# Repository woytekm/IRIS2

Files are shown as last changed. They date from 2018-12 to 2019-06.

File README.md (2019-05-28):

IRIS2 network radio project. This repository will contain all the necessary information required to build the unit.

Project images and video clips: https://drive.google.com/open?id=105BILNTAdYNRVomJvfbO0CPW3QA1uIXu

Currently we have here:
 - Code for core Iris application along with all necessary system scripts 
 - KiCad projects/schematics for all PCB's
 - STL's of all parts of the IRIS2 case
 - Some initial documentation
 
What we need to add:
 - More documentation
 - Detailed assembly instructions for all the PCB's and the unit itself
 - Detailed BOM for all of the PCB's, and additional stuff required to assemble the unit itself
 - Detailed instructions on how to make your own copy of IRIS2 firmware based on Raspbian (and/or firmware images)

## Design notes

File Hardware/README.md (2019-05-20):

This directory contains KiCad Projects of IRIS2 boards. Projects also contain Gerber files and schematics in PDF format.

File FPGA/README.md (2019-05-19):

This is JTAG indirect configuration file for Altera Cyclone IV EP4CE10 with EPCS16 flash memory.
Board used in project is from aliexpress.com "FPGA Board Store" seller.

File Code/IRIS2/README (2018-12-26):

packages needed on raspbian:

sudo apt-get install libxml2
sudo apt-get install libxml2-dev
sudo apt-get install libcurl3
sudo apt-get install libcurl4-openssl-dev

libbass-hardfp ARM

picotts:

sudo apt-get install libpopt-dev
sudo apt-get install libexpat1-dev

Hardware:

Raspberry Pi A+

speaker - Visaton FRWS 5 R

opamp 
 - NE5532

PSU board for opamp: 
 - LM2577 S ADJ
 - ICL7660
 - solid state relay (P/N?) 

RTC + NVRAM board
 - DS1397
 - Atmel 24C512 DIP8 (64KB)

display:
 - Winstar WEH001602

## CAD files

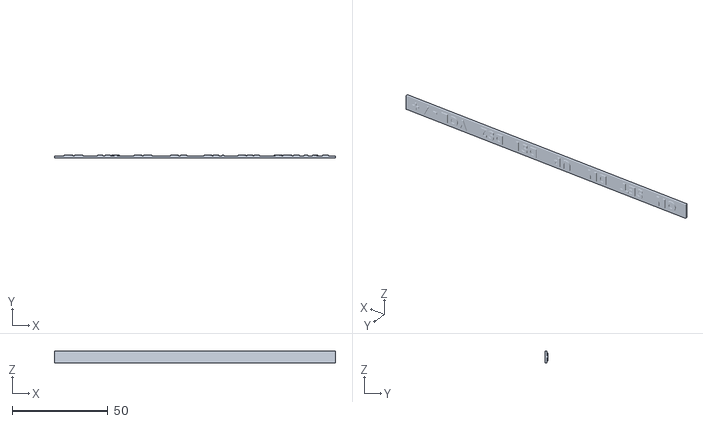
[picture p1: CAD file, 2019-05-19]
STL/2019-05-19/Main Unit - key descriptions v3.stl
147.0 x 1.60 x 6.50

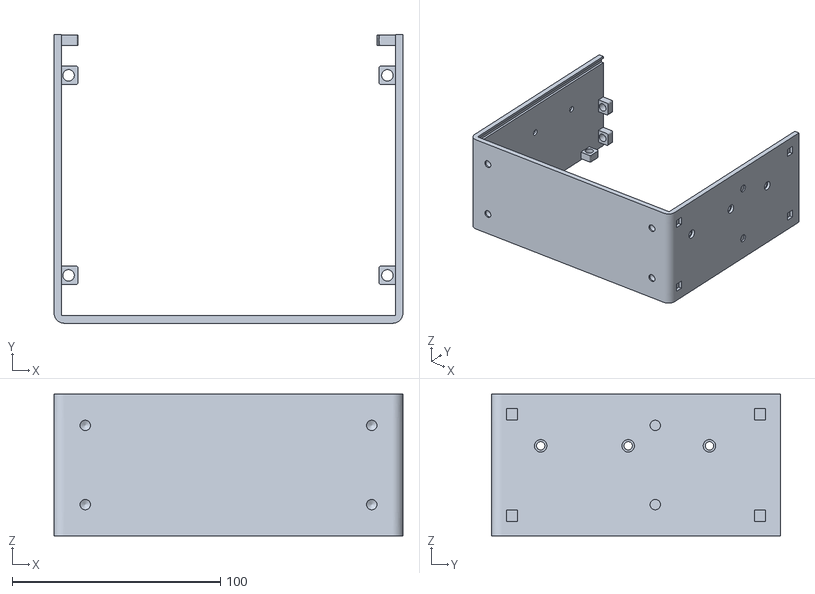
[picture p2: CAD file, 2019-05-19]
STL/2019-05-19/Main unit external shell v15.stl
167.5 x 138.5 x 68.0

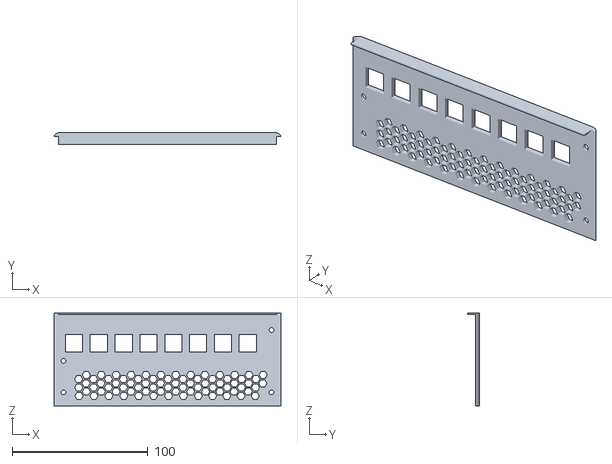
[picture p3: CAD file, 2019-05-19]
STL/2019-05-19/Main unit - top cover v24.stl
167.5 x 9.00 x 68.5

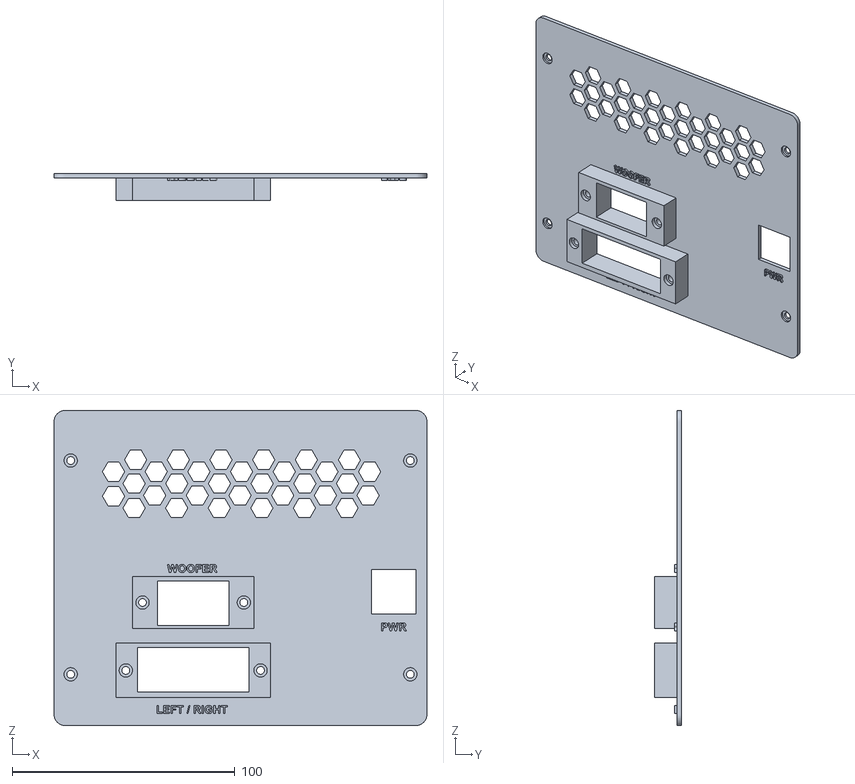
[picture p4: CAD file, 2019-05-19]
STL/2019-05-19/Main Unit - back cover.stl
167.5 x 12.1 x 141.5

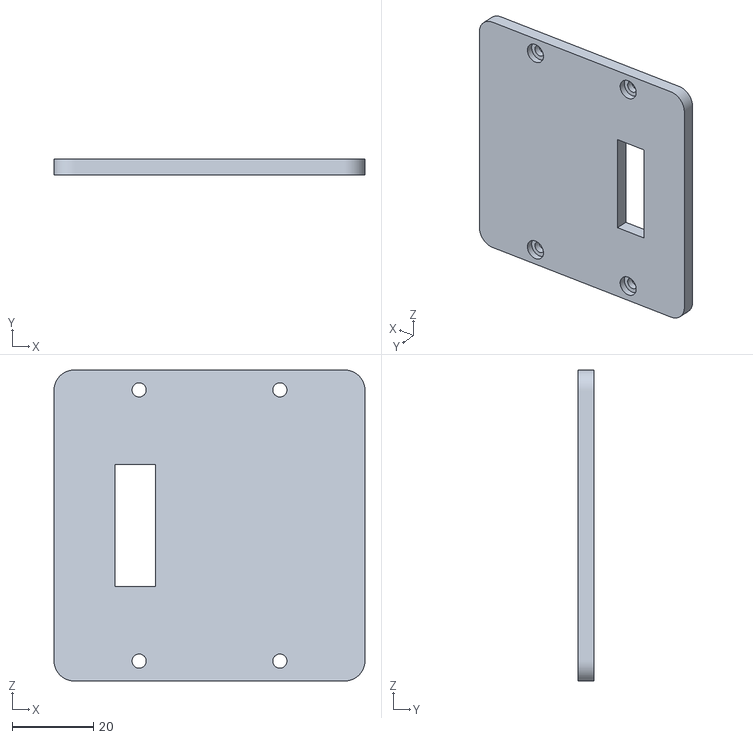
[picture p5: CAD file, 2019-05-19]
STL/2019-05-19/Satellite speaker back cover small v4.stl
76.7 x 4.00 x 76.7

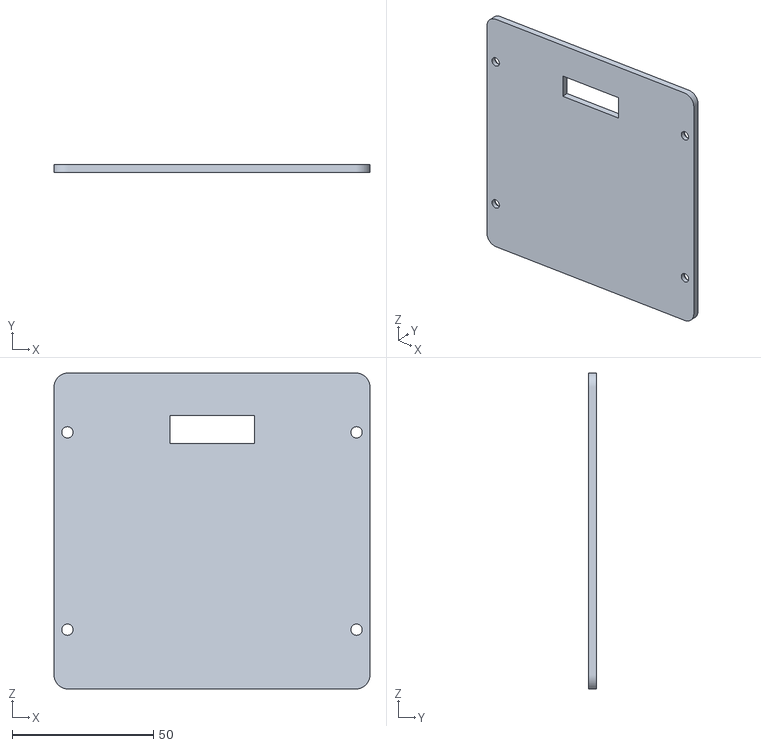
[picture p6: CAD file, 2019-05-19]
STL/2019-05-19/Subwoofer back cover v4.stl
111.8 x 3.00 x 111.8

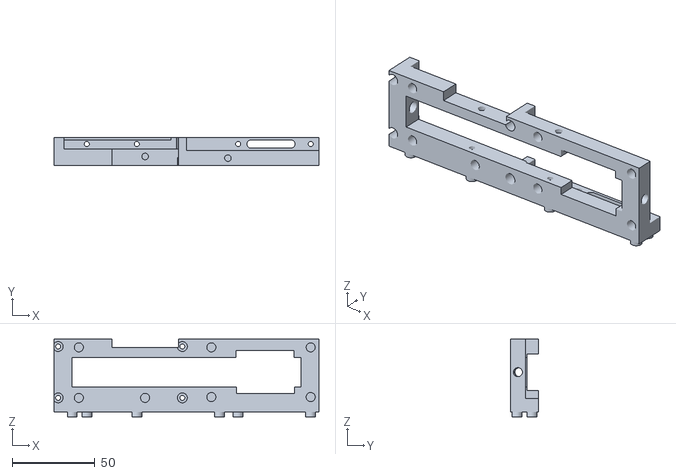
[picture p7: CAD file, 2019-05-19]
STL/2019-05-19/Upper LCD frame 160x40.stl
160.0 x 17.0 x 47.0

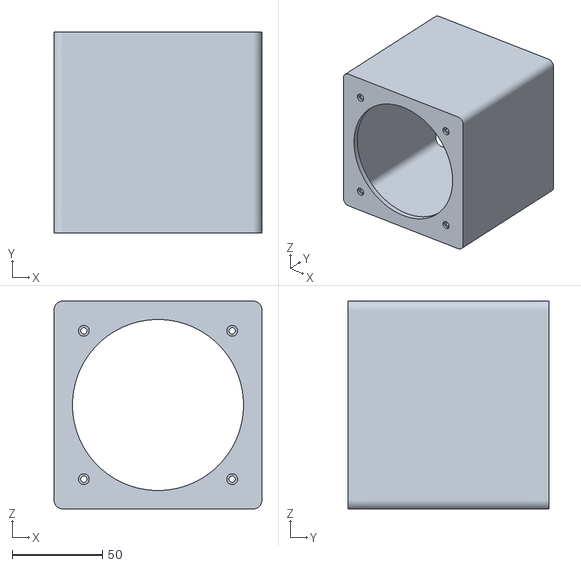
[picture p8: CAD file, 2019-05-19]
STL/2019-05-19/Subwoofer v9.stl
115.0 x 111.0 x 115.0

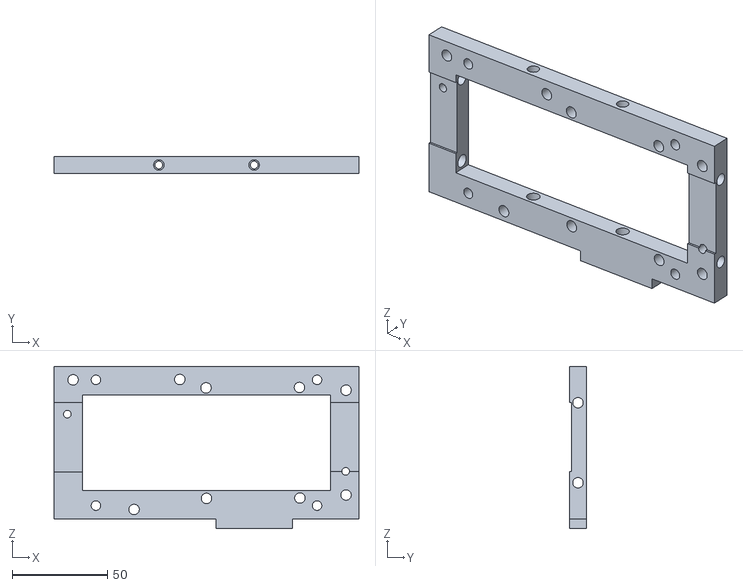
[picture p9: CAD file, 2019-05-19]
STL/2019-05-19/32x64 P2.5 mount frame single.stl
160.0 x 9.00 x 85.0

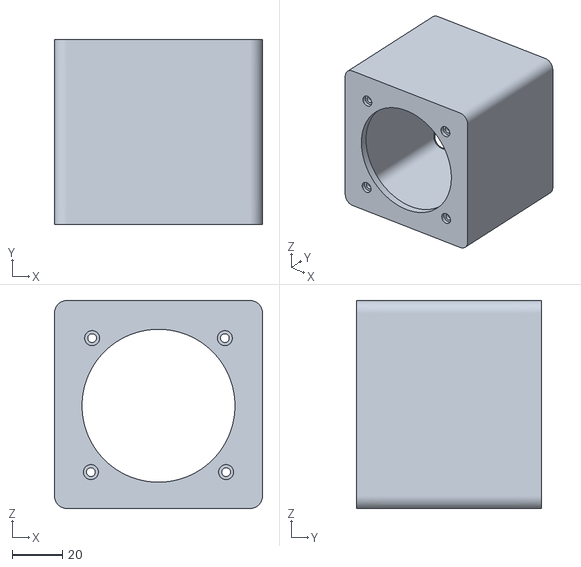
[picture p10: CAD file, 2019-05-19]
STL/2019-05-19/Satellite speaker small v7.stl
83.0 x 74.0 x 83.0

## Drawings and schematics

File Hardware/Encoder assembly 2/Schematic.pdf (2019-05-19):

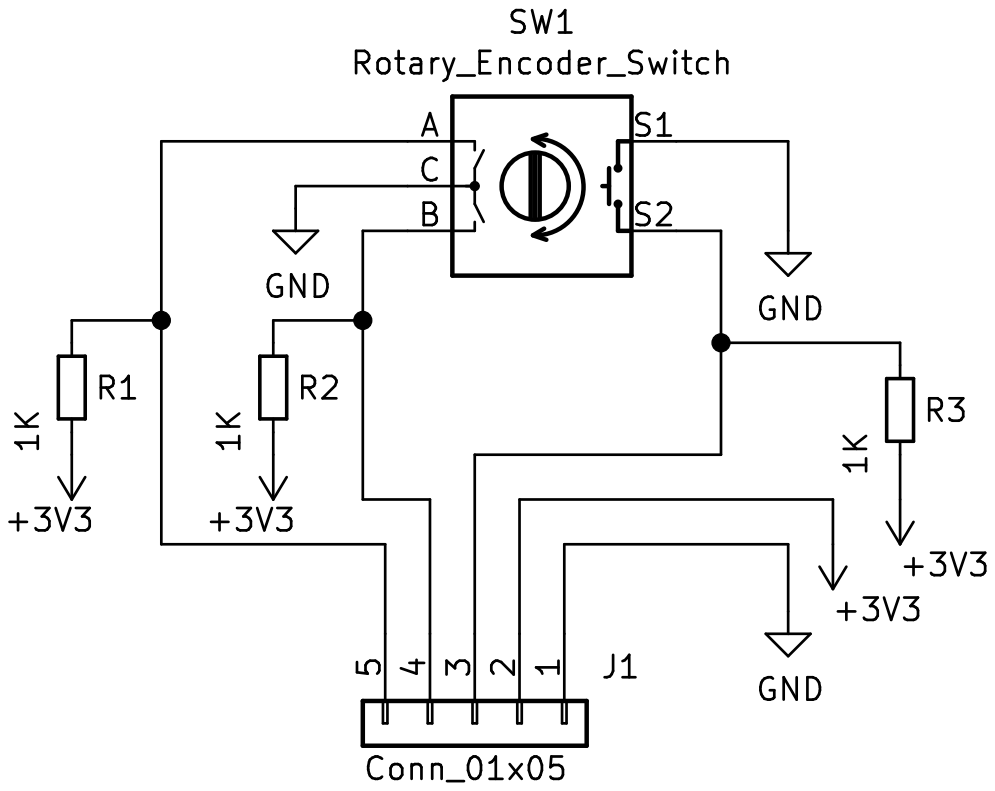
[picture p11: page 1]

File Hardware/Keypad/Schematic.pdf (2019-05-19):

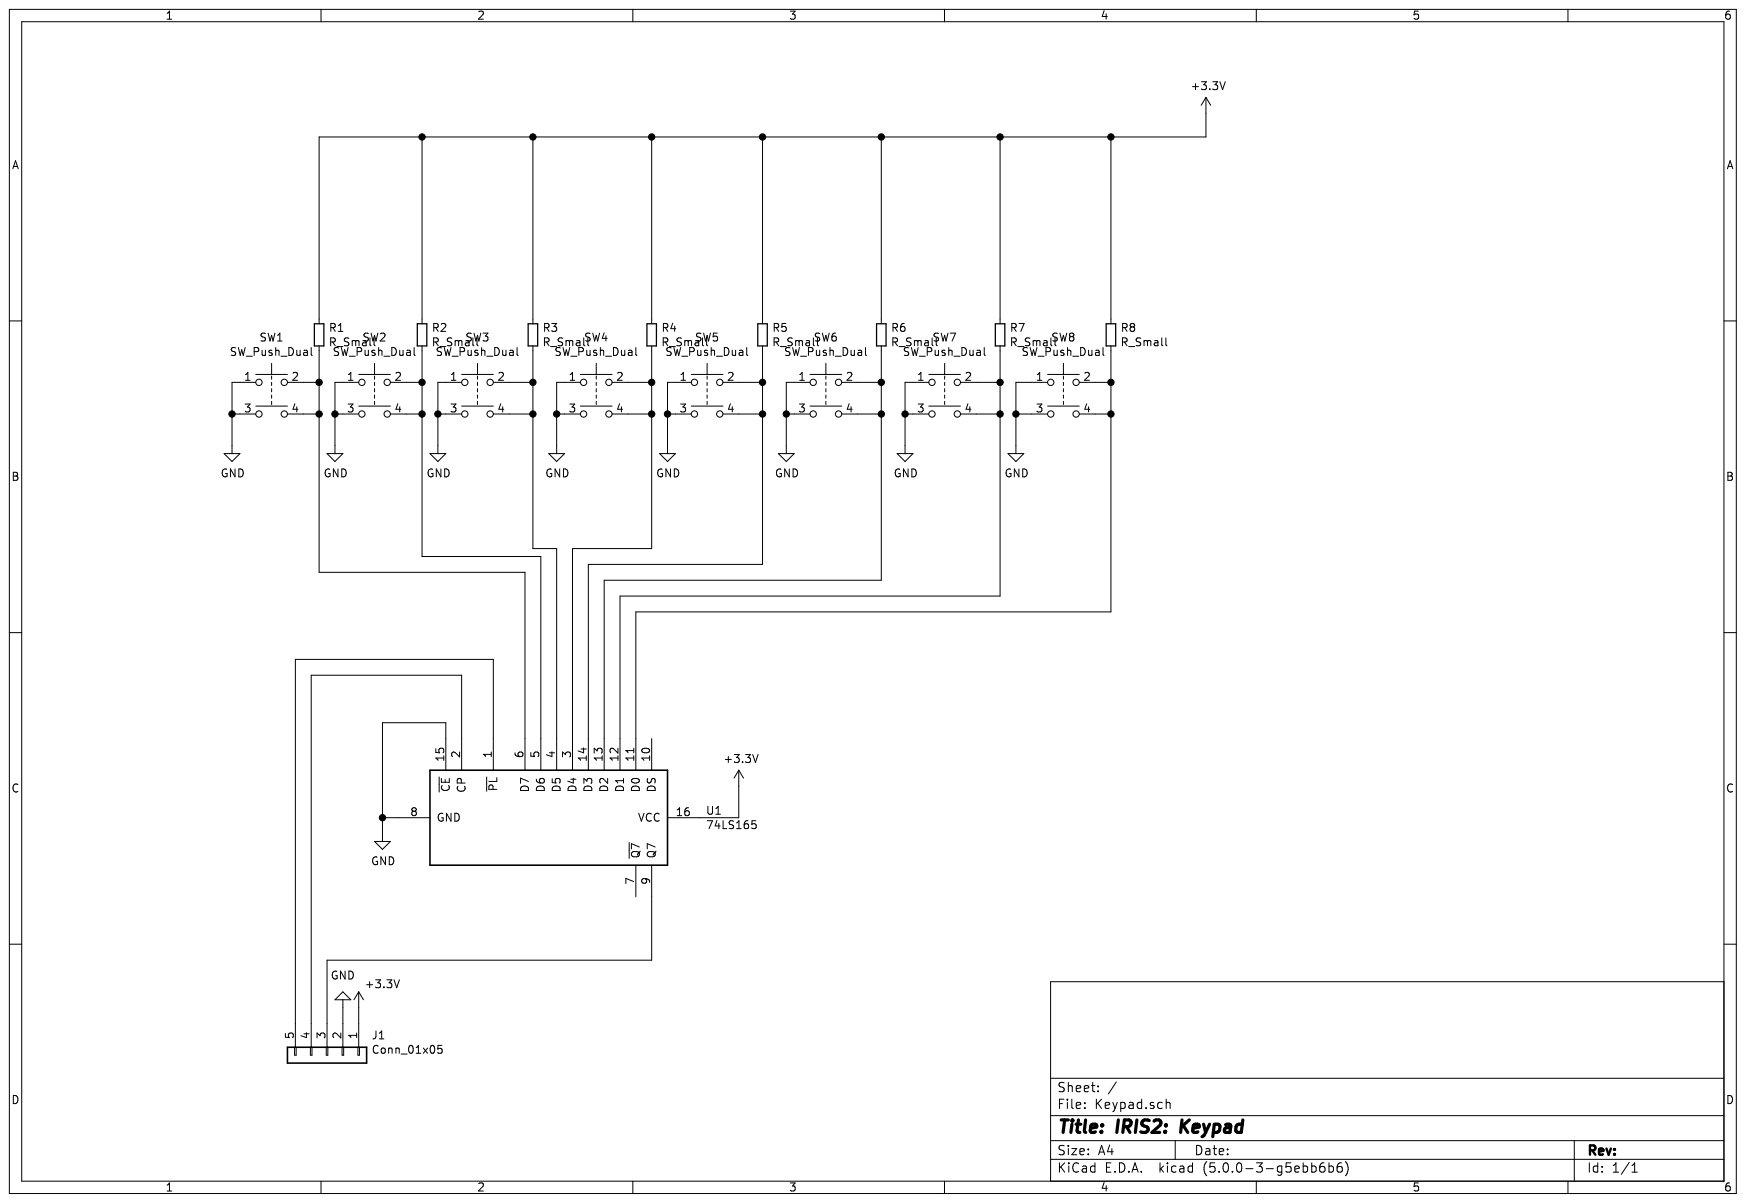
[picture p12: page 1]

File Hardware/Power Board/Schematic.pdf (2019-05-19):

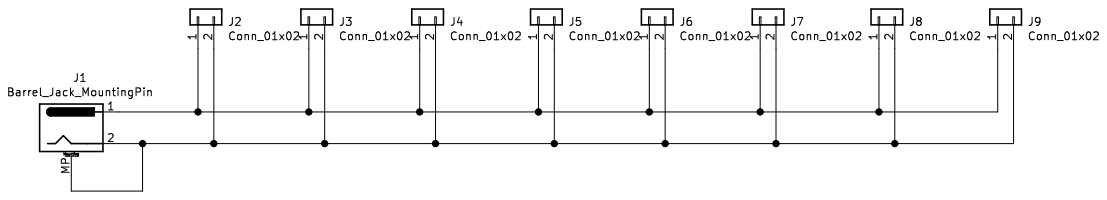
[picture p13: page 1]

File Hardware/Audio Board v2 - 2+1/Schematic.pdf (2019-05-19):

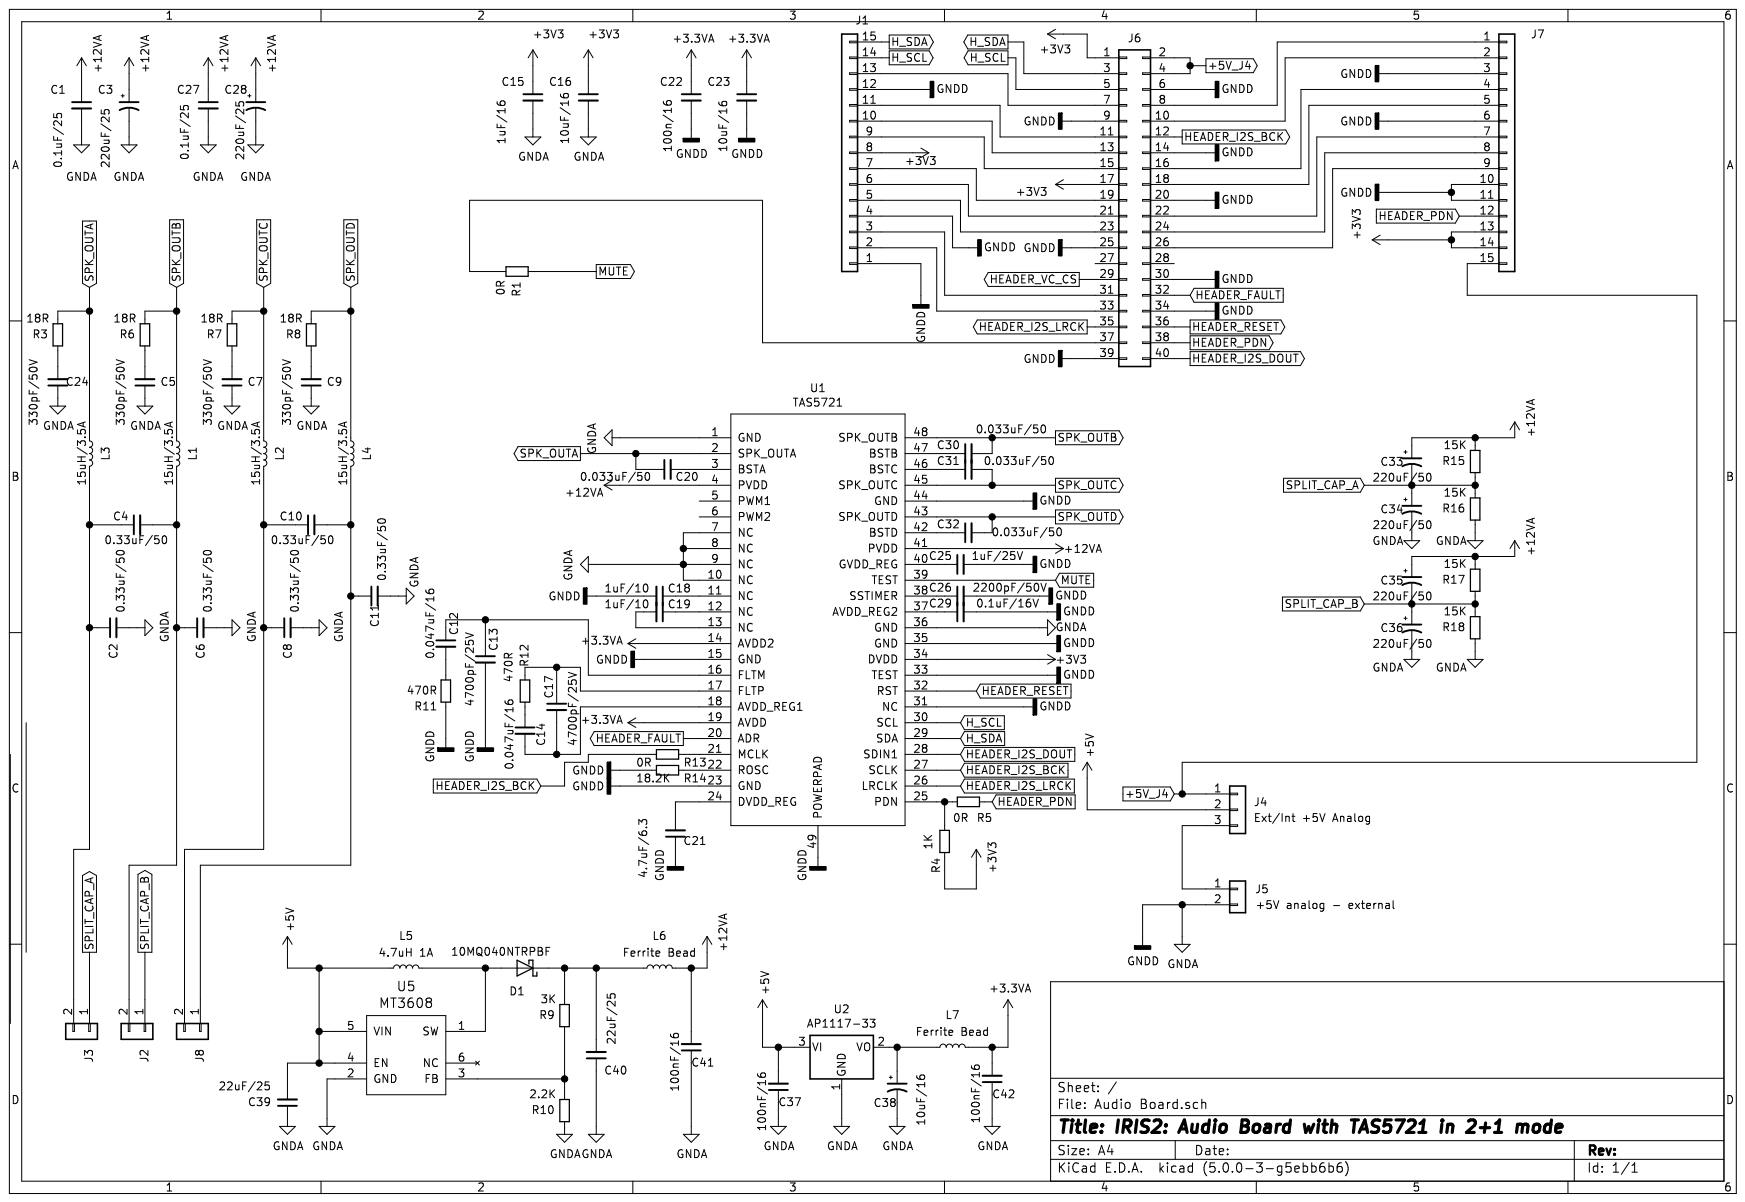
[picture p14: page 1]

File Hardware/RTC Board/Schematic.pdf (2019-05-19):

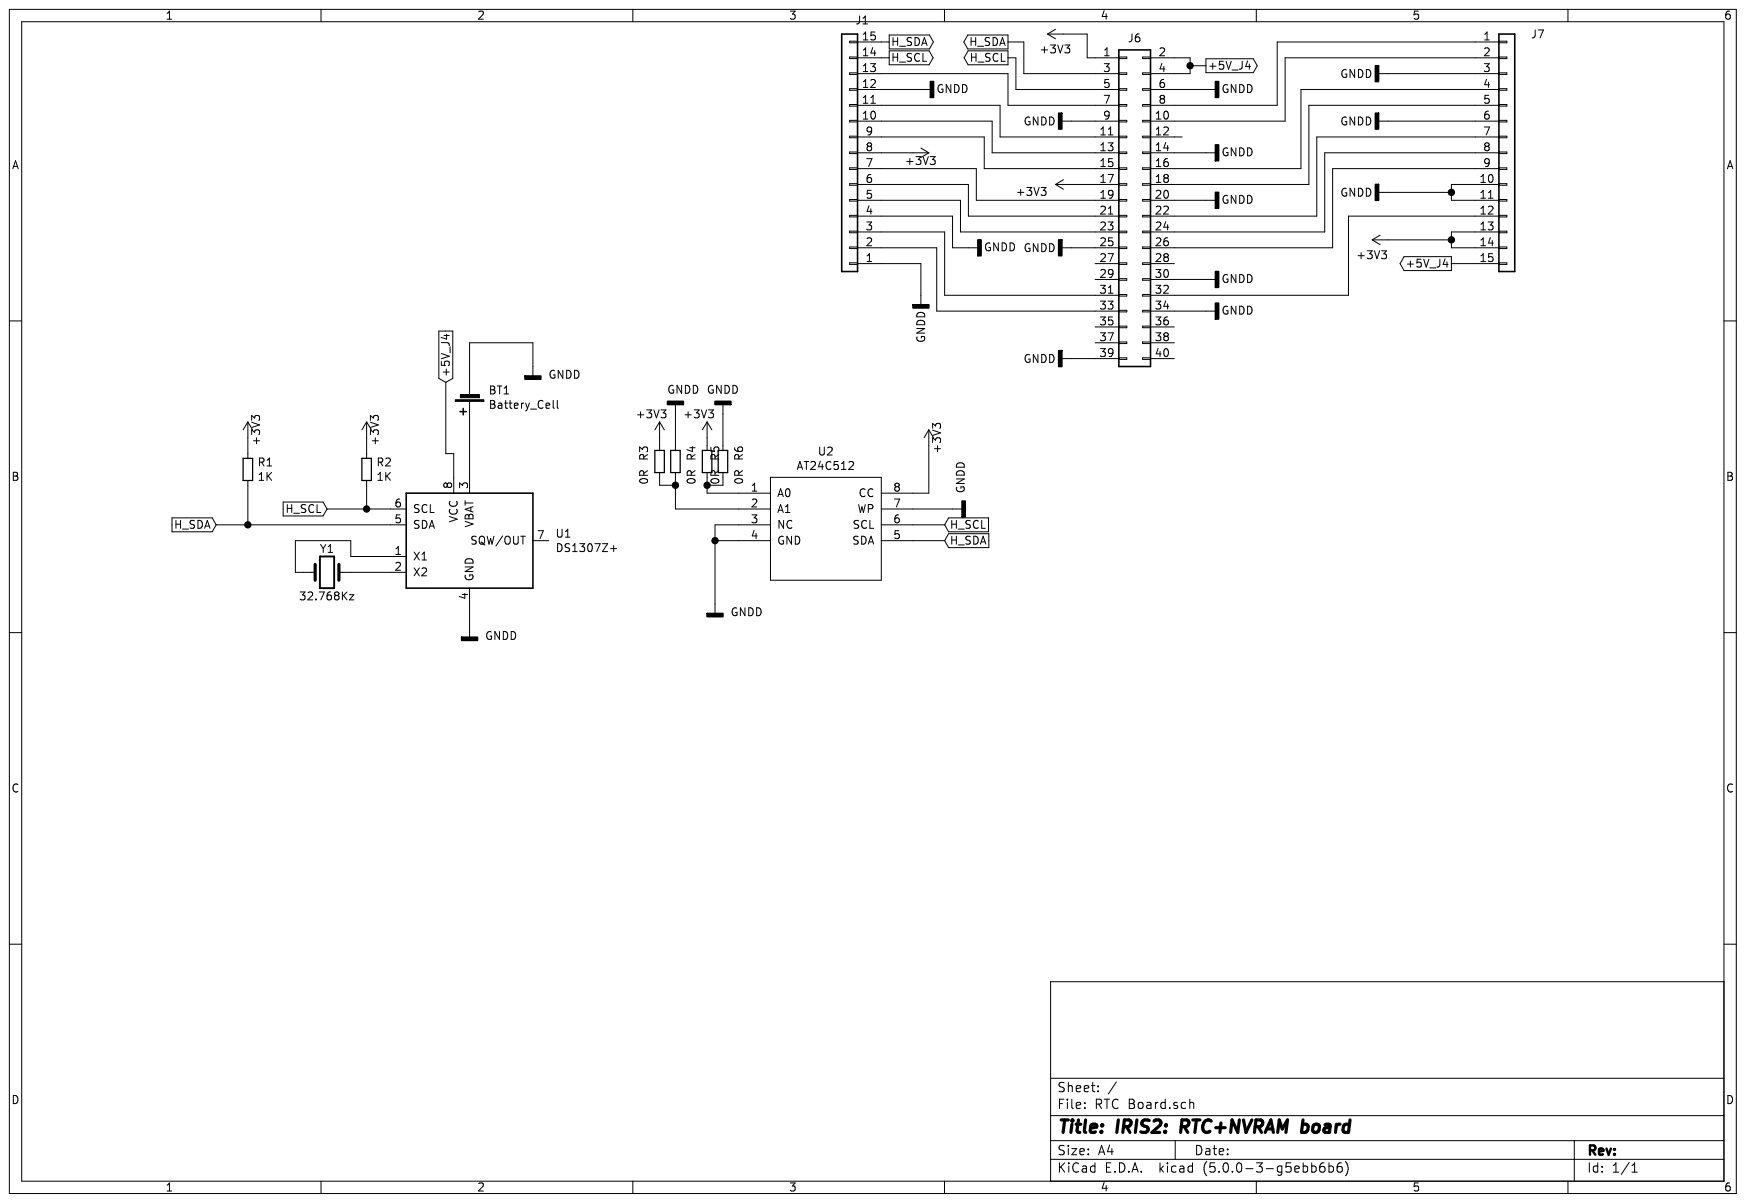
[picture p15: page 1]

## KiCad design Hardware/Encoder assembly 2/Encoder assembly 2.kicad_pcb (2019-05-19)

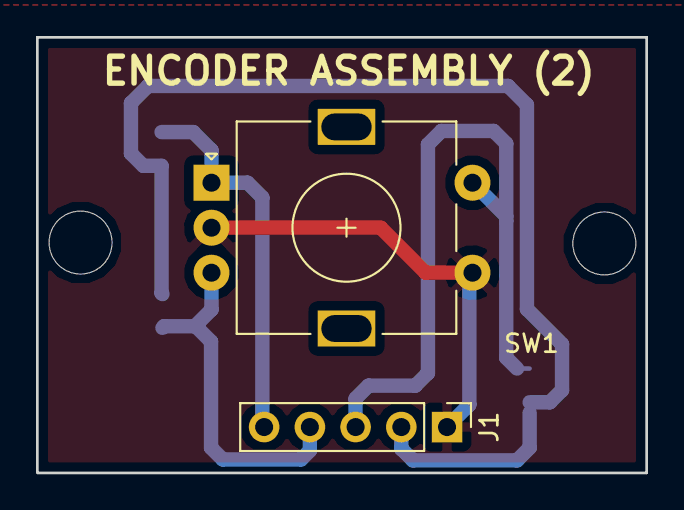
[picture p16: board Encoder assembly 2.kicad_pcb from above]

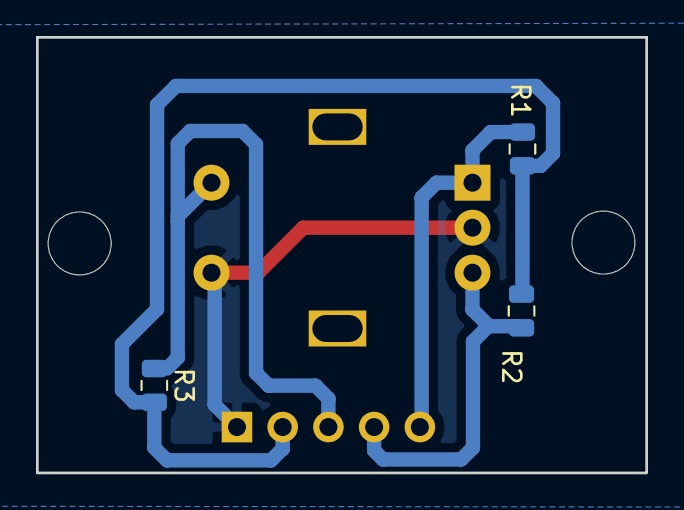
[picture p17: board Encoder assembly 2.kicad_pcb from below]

Board: 2 copper layers, 33.8 x 24.2 mm, 5 parts (3 on the bottom side), 5 nets.

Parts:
J1: Conn_01x05; PinHeader_1x05_P2.54mm_Vertical
R1, R2, R3: R_Small; R_0805_2012Metric
SW1: Rotary_Encoder_Switch; RotaryEncoder_Alps_EC11E-Switch_Vertical_H20mm

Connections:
+3V3: J1.2, R1.2, R2.2, R3.2
GND: J1.1, SW1.C, SW1.S1
unnamed: J1.3, R3.1, SW1.S2
unnamed: J1.4, R2.1, SW1.B
unnamed: J1.5, R1.1, SW1.A

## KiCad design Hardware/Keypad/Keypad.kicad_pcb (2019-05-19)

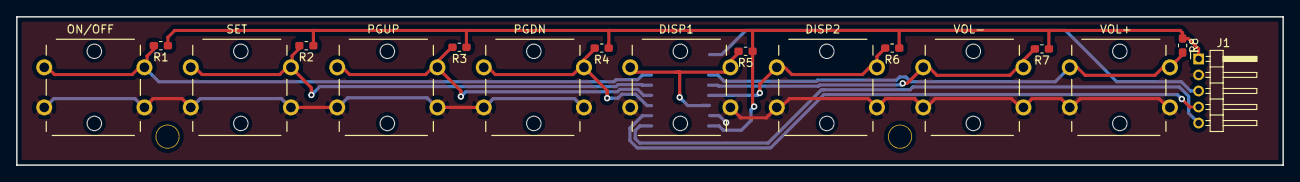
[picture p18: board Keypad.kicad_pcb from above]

Board: 2 copper layers, 158.0 x 18.5 mm, 18 parts (1 on the bottom side), 13 nets.

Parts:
DISP1, DISP2: SW_Push_Dual; B3F-4050
J1: Conn_01x05; PinHeader_1x05_P2.00mm_Horizontal
ON/OFF: SW_Push_Dual; B3F-4050
PGDN: SW_Push_Dual; B3F-4050
PGUP: SW_Push_Dual; B3F-4050
R1, R2, R3, R4, R5, R6, R7, R8: R_Small; R_0603_1608Metric_Pad1.05x0.95mm_HandSolder
SET: SW_Push_Dual; B3F-4050
U1: 74LS165; SOIC-16W_5.3x10.2mm_P1.27mm
VOL+: SW_Push_Dual; B3F-4050
VOL-: SW_Push_Dual; B3F-4050

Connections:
+3V3: J1.1, R1.1, R2.1, R3.1, R4.1, R5.1, R6.1, R7.1, R8.1, U1.16
GND: DISP1.1, DISP1.3, DISP2.1, DISP2.3, J1.2, ON/OFF.1, ON/OFF.3, PGDN.1, PGDN.3, PGUP.1, PGUP.3, SET.1, SET.3, U1.8, U1.15, VOL+.1, VOL+.3, VOL-.1, VOL-.3
unnamed: J1.3, U1.9
unnamed: J1.4, U1.2
unnamed: J1.5, U1.1
unnamed: ON/OFF.2, ON/OFF.4, R1.2, U1.6
unnamed: R2.2, SET.2, SET.4, U1.5
unnamed: PGUP.2, PGUP.4, R3.2, U1.4
unnamed: PGDN.2, PGDN.4, R4.2, U1.3
unnamed: DISP1.2, DISP1.4, R5.2, U1.14
unnamed: DISP2.2, DISP2.4, R6.2, U1.13
unnamed: R7.2, U1.12, VOL-.2, VOL-.4
unnamed: R8.2, U1.11, VOL+.2, VOL+.4

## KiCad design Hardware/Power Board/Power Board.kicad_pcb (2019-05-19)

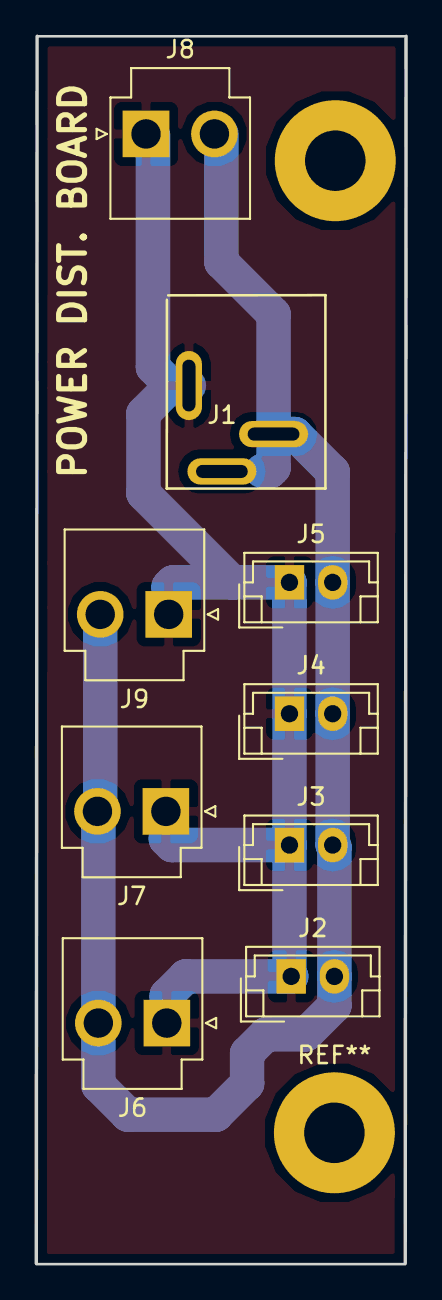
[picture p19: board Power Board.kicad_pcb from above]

Board: 2 copper layers, 21.4 x 71.0 mm, 9 parts (0 on the bottom side), 2 nets.

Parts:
J1: Barrel_Jack_MountingPin; Barrel Jack Vertical
J2, J3, J4, J5: Conn_01x02; JST_EH_B02B-EH-A_1x02_P2.50mm_Vertical
J6, J7, J8, J9: Conn_01x02; JST_VH_B2P-VH-B_1x02_P3.96mm_Vertical

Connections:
unnamed: J1.1, J2.1, J3.1, J4.1, J5.1, J6.1, J7.1, J8.1, J9.1
unnamed: J1.2, J2.2, J3.2, J4.2, J5.2, J6.2, J7.2, J8.2, J9.2

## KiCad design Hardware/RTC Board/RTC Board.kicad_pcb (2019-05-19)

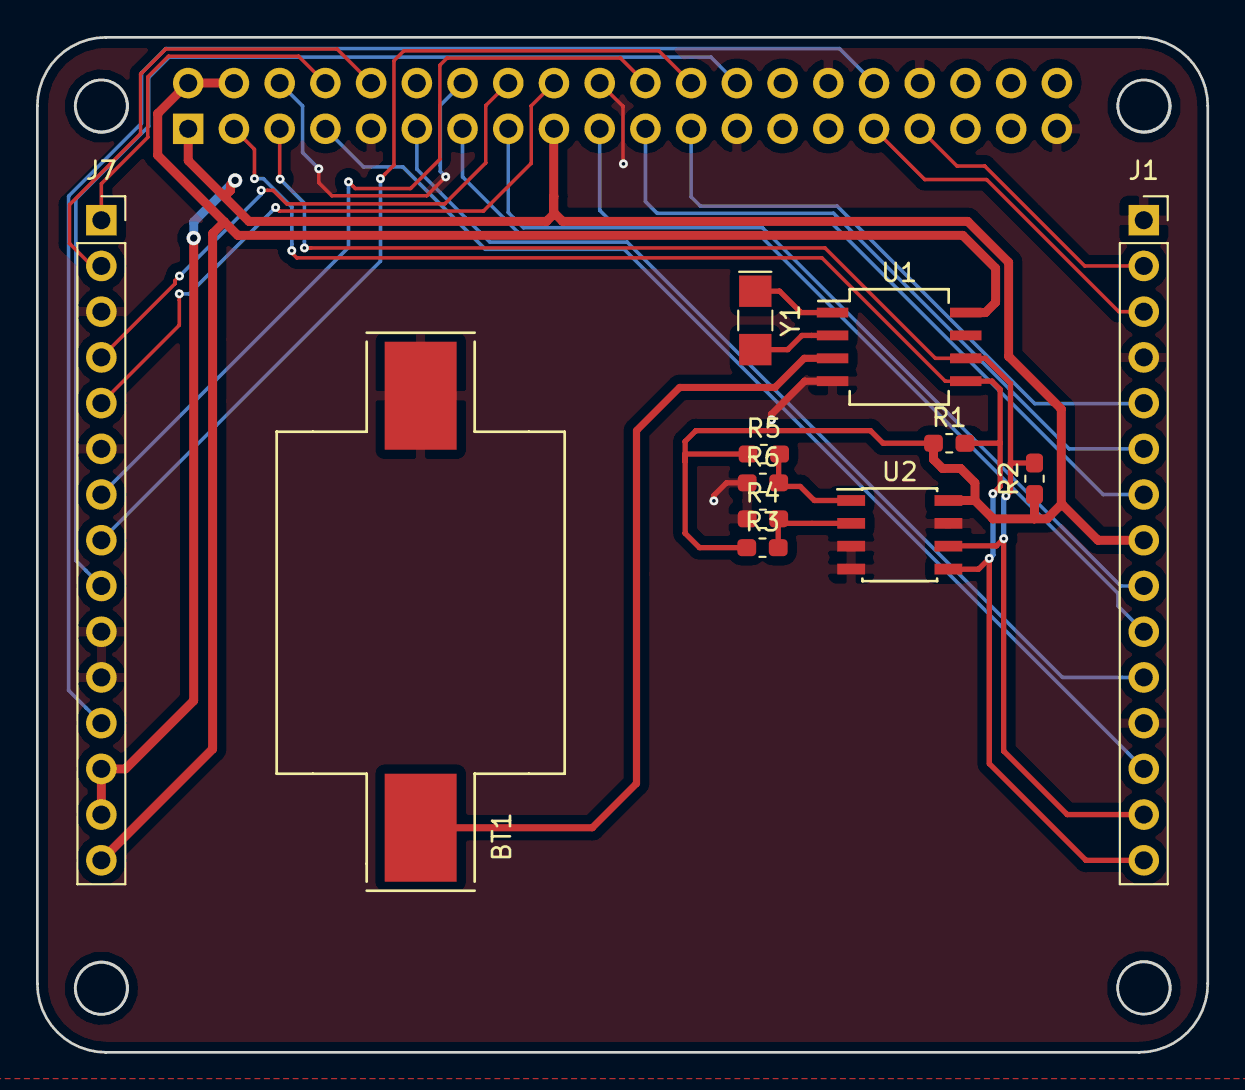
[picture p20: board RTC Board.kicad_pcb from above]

Board: 2 copper layers, 65.0 x 56.4 mm, 13 parts (1 on the bottom side), 27 nets.

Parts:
BT1: Battery_Cell; CH29-CR2032
J1, J7: Conn_01x15; PinSocket_1x15_P2.54mm_Vertical
J6: Conn_02x20_Odd_Even; PinSocket_2x20_P2.54mm_Vertical
R1, R2: 1K; R_0603_1608Metric_Pad1.05x0.95mm_HandSolder
R3, R4, R5, R6: 0R; R_0603_1608Metric_Pad1.05x0.95mm_HandSolder
U1: DS1307Z+; SO-8_5.3x6.2mm_P1.27mm
U2: AT24C512; SOIC-8_3.9x4.9mm_P1.27mm
Y1: 32.768Kz; Crystal_SMD_G8-2Pin_3.2x1.5mm_HandSoldering

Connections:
+3V3: J1.8, J6.1, J6.17, J7.13, J7.14, R1.1, R2.1, R3.1, R5.1, U2.8
+5V_J4: J6.2, J6.4, J7.15, U1.8
GNDD: BT1.2, J1.1, J1.4, J1.12, J6.6, J6.9, J6.14, J6.20, J6.25, J6.30, J6.34, J6.39, J7.3, J7.6, J7.10, J7.11, R4.1, R6.1, U1.4, U2.3, U2.4, U2.7
H_SCL: J1.14, J6.5, R2.2, U1.6, U2.6
H_SDA: J1.15, J6.3, R1.2, U1.5, U2.5
unnamed: BT1.1, U1.3
unnamed: J1.2, J6.33
unnamed: J1.3, J6.31
unnamed: J1.5, J6.23
unnamed: J1.6, J6.21
unnamed: J1.7, J6.19
unnamed: J1.9, J6.15
unnamed: J1.10, J6.13
unnamed: J1.11, J6.11
unnamed: J1.13, J6.7
unnamed: J6.8, J7.1
unnamed: J6.10, J7.2
unnamed: J6.16, J7.4
unnamed: J6.18, J7.5
unnamed: J6.22, J7.7
unnamed: J6.24, J7.8
unnamed: J6.26, J7.9
unnamed: J6.32, J7.12
unnamed: R3.2, R4.2, U2.2
unnamed: R5.2, R6.2, U2.1
unnamed: U1.1, Y1.1
unnamed: U1.2, Y1.2

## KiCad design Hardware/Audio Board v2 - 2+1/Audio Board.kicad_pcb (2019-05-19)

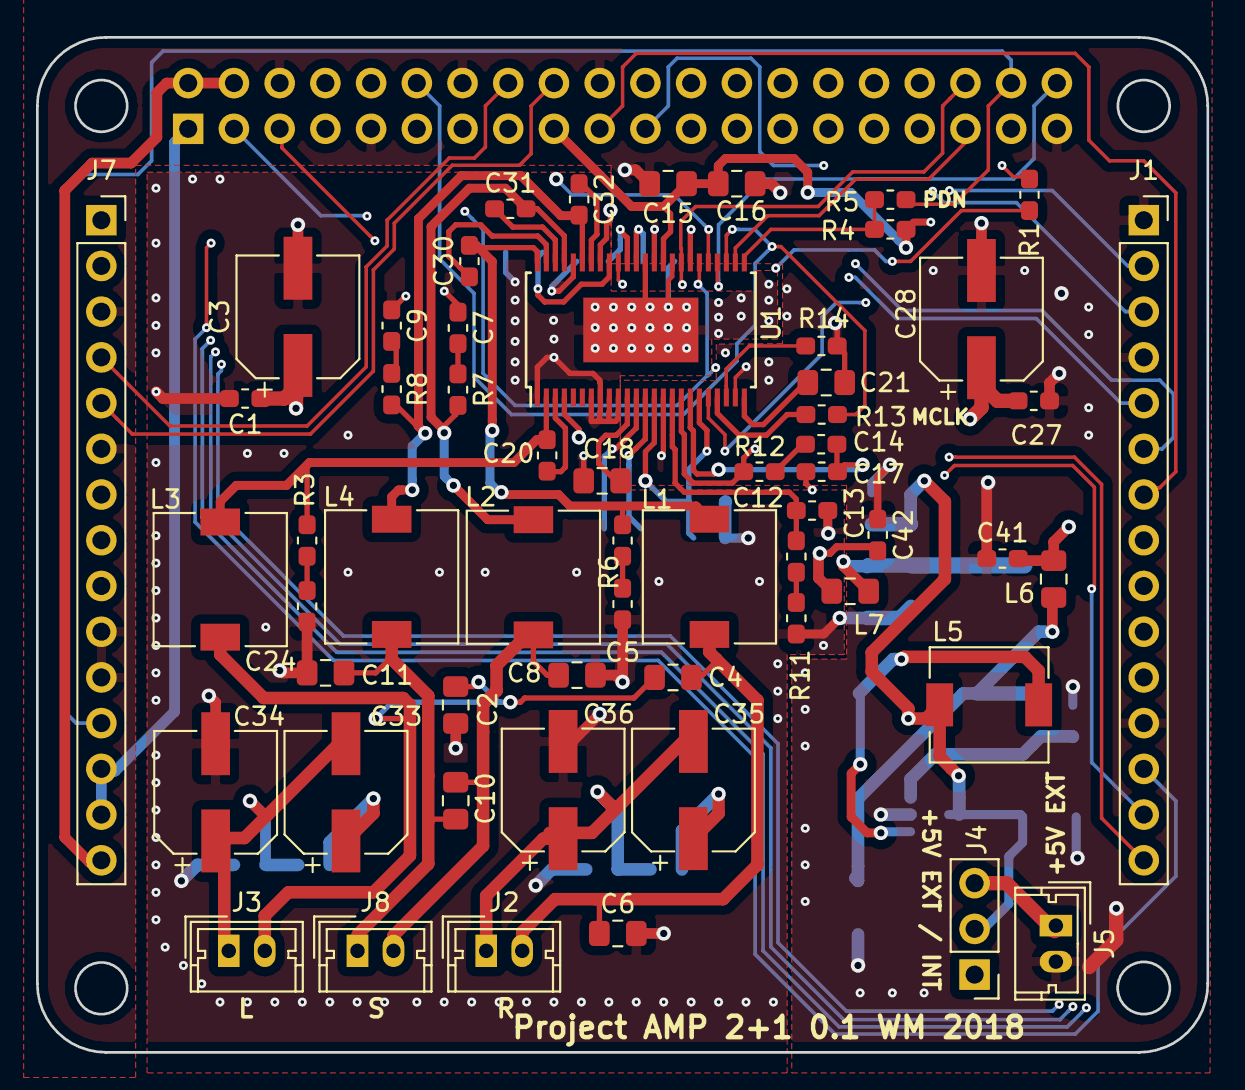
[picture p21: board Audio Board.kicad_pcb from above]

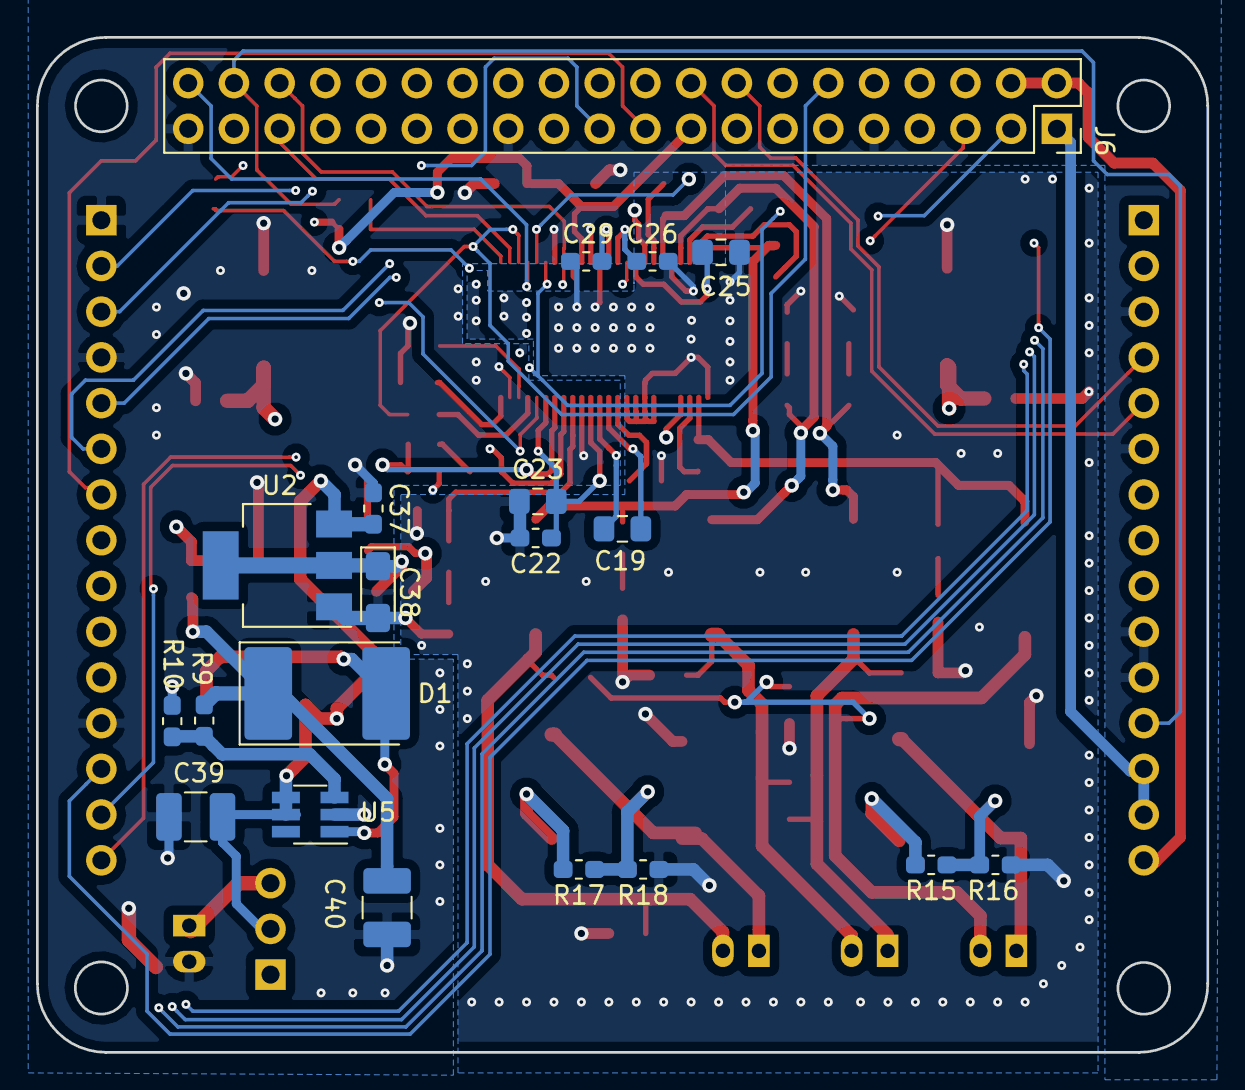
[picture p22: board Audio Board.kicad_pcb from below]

Board: 4 copper layers, 65.0 x 56.4 mm, 78 parts (20 on the bottom side), 70 nets.

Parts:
C1, C27: 0.1uF/25; C_0603_1608Metric_Pad1.05x0.95mm_HandSolder
C2, C4, C6, C8, C10, C11: 0.33uF/50; C_0805_2012Metric_Pad1.15x1.40mm_HandSolder
C3, C28: 220uF/25; CP_Elec_6.3x7.7
C5, C7, C9, C24: 330pF/50V; C_0603_1608Metric_Pad1.05x0.95mm_HandSolder
C12, C14: 0.047uF/16; C_0603_1608Metric_Pad1.05x0.95mm_HandSolder
C13, C17: 4700pF/25V; C_0603_1608Metric_Pad1.05x0.95mm_HandSolder
C15: 1uF/16; C_0805_2012Metric_Pad1.15x1.40mm_HandSolder
C16, C23: 10uF/16; C_0805_2012Metric_Pad1.15x1.40mm_HandSolder
C18, C19: 1uF/10; C_0805_2012Metric_Pad1.15x1.40mm_HandSolder
C20, C30, C31, C32: 0.033uF/50; C_0603_1608Metric_Pad1.05x0.95mm_HandSolder
C21: 4.7uF/6.3; C_0805_2012Metric_Pad1.15x1.40mm_HandSolder
C22: 100n/16; C_0603_1608Metric_Pad1.05x0.95mm_HandSolder
C25: 1uF/25V; C_0805_2012Metric_Pad1.15x1.40mm_HandSolder
C26: 2200pF/50V; C_0603_1608Metric_Pad1.05x0.95mm_HandSolder
C29: 0.1uF/16V; C_0603_1608Metric_Pad1.05x0.95mm_HandSolder
C33, C34, C35, C36: 220uF/50; CP_Elec_6.3x7.7
C37, C41, C42: 100nF/16; C_0603_1608Metric_Pad1.05x0.95mm_HandSolder
C38: 10uF/16; CP_EIA-3216-18_Kemet-A_Pad1.58x1.35mm_HandSolder
C39, C40: 22uF/25; C_1210_3225Metric_Pad1.42x2.65mm_HandSolder
D1: 10MQ040NTRPBF; D_3220_8050Metric_Pad2.65x5.15mm_HandSolder
J1, J7: Conn_01x15; PinSocket_1x15_P2.54mm_Vertical
J2, J3, J8: Conn_01x02; Molex_Micro-Latch_53253-0270_1x02_P2.00mm_Vertical
J4: Ext/Int +5V Analog; PinHeader_1x03_P2.54mm_Vertical
J5: +5V analog - external; Molex_Micro-Latch_53253-0270_1x02_P2.00mm_Vertical
J6: Conn_02x20_Odd_Even; PinSocket_2x20_P2.54mm_Vertical
L1, L2, L3, L4: 15uH/3.5A; L_7.3x7.3_H3.5
L5: 4.7uH 1A; L_6.3x6.3_H3
L6, L7: Ferrite Bead; L_0805_2012Metric_Pad1.15x1.40mm_HandSolder
R1, R5, R13: 0R; R_0603_1608Metric_Pad1.05x0.95mm_HandSolder
R3, R6, R7, R8: 18R; R_0603_1608Metric_Pad1.05x0.95mm_HandSolder
R4: 1K; R_0603_1608Metric_Pad1.05x0.95mm_HandSolder
R9: 3K; R_0603_1608Metric_Pad1.05x0.95mm_HandSolder
R10: 2.2K; R_0603_1608Metric_Pad1.05x0.95mm_HandSolder
R11, R12: 470R; R_0603_1608Metric_Pad1.05x0.95mm_HandSolder
R14: 18.2K; R_0603_1608Metric_Pad1.05x0.95mm_HandSolder
R15, R16, R17, R18: 15K; R_0603_1608Metric_Pad1.05x0.95mm_HandSolder
U1: TAS5721; HTSSOP48
U2: AP1117-33; SOT-223-3_TabPin2
U5: MT3608; SOT-23-6_Handsoldering

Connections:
+3.3VA: C22.1, C23.1, C42.2, L7.2, U1.14, U1.19
+3V3: C15.1, C16.1, J1.8, J6.1, J6.17, J7.13, J7.14, R4.1, U1.34
+5V: C37.2, C39.2, J4.2, L5.1, U2.3, U5.4, U5.5
+5V_J4: J4.1, J6.2, J6.4, J7.15
+12VA: C1.1, C3.1, C27.1, C28.1, C33.1, C35.1, C41.2, L6.2, R15.2, R17.2, U1.4, U1.41
GNDA: C1.2, C2.2, C3.2, C5.1, C6.2, C7.1, C8.2, C9.1, C11.2, C13.2, C15.2, C16.2, C18.2, C21.1, C22.2, C23.2, C24.1, C25.2, C26.2, C27.2, C28.2, C29.2, C34.2, C36.2, C37.1, C38.2, C39.1, C40.1, C41.1, C42.1, J1.1, J1.4, J1.12, J5.2, J6.6, J6.9, J6.14, J6.20, J6.25, J6.30, J6.34, J6.39, J7.3, J7.6, J7.10, J7.11, R10.1, R11.1, R14.2, R16.1, R18.1, U1.1, U1.7, U1.8, U1.9, U1.10, U1.15, U1.23, U1.31, U1.33, U1.35, U1.36, U1.44, U1.49, U2.1, U5.2
HEADER_FAULT: J6.32, U1.20
HEADER_I2S_BCK: J6.12, R13.2, U1.27
HEADER_I2S_DOUT: J6.40, U1.28
HEADER_I2S_LRCK: J6.35, U1.26
HEADER_PDN: J6.38, J7.12, R5.1
HEADER_RESET: J6.36, U1.32
H_SCL: J1.14, J6.5, U1.30
H_SDA: J1.15, J6.3, U1.29
MUTE: R1.1, U1.39
unnamed: C2.1, C4.1, J3.2, L3.2
unnamed: C4.2, C6.1, J2.2, L1.2
unnamed: C5.2, R6.1
unnamed: C7.2, R7.1
unnamed: C9.2, R8.1
unnamed: C8.1, C10.1, J8.2, L2.2
unnamed: C10.2, C11.1, J8.1, L4.2
unnamed: C12.1, C13.1, U1.16
unnamed: C12.2, R11.2
unnamed: C14.1, R12.1
unnamed: C14.2, C17.2, U1.18
unnamed: C17.1, R12.2, U1.17
unnamed: C18.1, U1.11
unnamed: C19.1, U1.12
unnamed: C19.2, U1.13
unnamed: C20.2, U1.3
unnamed: C21.2, U1.24
unnamed: C24.2, R3.1
unnamed: C25.1, U1.40
unnamed: C26.1, U1.38
unnamed: C29.1, U1.37
unnamed: C30.1, U1.47
unnamed: C31.1, U1.46
unnamed: C32.1, U1.42
unnamed: C38.1, L7.1, U2.2
unnamed: C40.2, D1.1, L6.1, R9.2
unnamed: D1.2, L5.2, U5.1
unnamed: J1.2, J6.33
unnamed: J1.3, J6.31
unnamed: J1.5, J6.23
unnamed: J1.6, J6.21
unnamed: J1.7, J6.19
unnamed: J1.9, J6.15
unnamed: J1.10, J6.13
unnamed: J1.11, J6.11
unnamed: J1.13, J6.7
unnamed: J4.3, J5.1
unnamed: J6.8, J7.1
unnamed: J6.10, J7.2
unnamed: J6.16, J7.4
unnamed: J6.18, J7.5
unnamed: J6.22, J7.7
unnamed: J6.24, J7.8
unnamed: J6.26, J7.9
unnamed: J6.37, R1.2
unnamed: R4.2, R5.2, U1.25
unnamed: R9.1, R10.2, U5.3
unnamed: R13.1, U1.21
unnamed: R14.1, U1.22
SPK_OUTA: C20.1, L3.1, R3.2, U1.2
SPK_OUTB: C30.2, L1.1, R6.2, U1.48
SPK_OUTC: C31.2, L2.1, R7.2, U1.45
SPK_OUTD: C32.2, L4.1, R8.2, U1.43
SPLIT_CAP_A: C33.2, C34.1, J3.1, R15.1, R16.2
SPLIT_CAP_B: C35.2, C36.1, J2.1, R17.1, R18.2

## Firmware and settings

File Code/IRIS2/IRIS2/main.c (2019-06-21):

#include "global.h"
#include "version.h"
#include "system.h"
#include "plclock.h"
#include "rss.h"
#include "player.h"
#include "keyboard.h"
#include "WEH001602-lib.h"
#include "setup.h"
#include "tts.h"
#include "config.h"
#include "alarm.h"
#include "wifi_signal.h"
#include "audio.h"
#include "bluetooth.h"
#include "matrix.h"
#include "weather.h"


main(int argc, char **argv)
 {

  iris_persistence_data_t persistence_data;
  int pid;
 
  if(argc > 1)
   if(strstr(argv[1], "-d") != NULL)
    {
     G_debug_info_active = 1;
     G_logfile_handle = fopen(DEBUG_FILE,"w");
    }
   else
    G_debug_info_active = 0;
 
  PL_debug("main: Iris version %d.%d. Compiled on: %s. Starting...", IRIS_VER_MAJOR, IRIS_VER_MINOR, IRIS_COMPILE_TIME);

  PL_init();
 
  pid = fork(); 
  if (pid < 0)
   {
      /* Could not fork  */
     exit(EXIT_FAILURE);
   }
  if (pid > 0)
   {
     /* Child created ok, so exit parent process  */
     exit(EXIT_SUCCESS);
   }

  PL_load_config(&G_config_data);
  PL_parse_config_buffer(&G_config_data);

  PL_debug("main: starting Iris tasks");

  G_iris_tasks[TASK_CLOCK] = PL_start_task(TASK_CLOCK, PL_clock_thread, NULL, SCHED_RR, 90);
  G_iris_tasks[TASK_SNOOZE] = PL_start_task(TASK_SNOOZE, PL_snooze_timer_thread, NULL, SCHED_RR, 70);
  G_iris_tasks[TASK_RSS] = PL_start_task(TASK_RSS, PL_rss_reader_thread, NULL, SCHED_RR, 85);
  G_iris_tasks[TASK_PLAYER] = PL_start_task(TASK_PLAYER, PL_player_thread, NULL, SCHED_RR, 86);
  G_iris_tasks[TASK_KEYBOARD] = PL_start_task(TASK_KEYBOARD, PL_keyboard_thread, NULL, SCHED_RR, 87); 
  G_iris_tasks[TASK_PLAYER_DISPLAY] = PL_start_task(TASK_PLAYER_DISPLAY, PL_player_display_thread, NULL, SCHED_RR, 95);
  G_iris_tasks[TASK_SETUP] = PL_start_task(TASK_SETUP, PL_setup_thread, NULL, SCHED_RR, 80);
  G_iris_tasks[TASK_TTS_INDICATOR] = PL_start_task(TASK_TTS_INDICATOR, PL_TTS_indicator_thread, NULL, SCHED_RR, 54);
  G_iris_tasks[TASK_ALARM] = PL_start_task(TASK_ALARM, PL_alarm_thread, NULL, SCHED_RR, 53);
  G_iris_tasks[TASK_ALARM_INDICATOR] = PL_start_task(TASK_ALARM_INDICATOR, PL_alarm_indicator_thread, NULL, SCHED_RR, 52);
  G_iris_tasks[TASK_EXT_CMDS] = PL_start_task(TASK_EXT_CMDS, PL_command_thread, NULL, SCHED_RR, 40);
  G_iris_tasks[TASK_TTS] = PL_start_task(TASK_TTS, PL_TTS_thread, NULL, SCHED_BATCH, 0);
  G_iris_tasks[TASK_WIFI_INDICATOR] = PL_start_task(TASK_WIFI_INDICATOR, PL_wifi_signal_thread, NULL, SCHED_BATCH, 0);
  G_iris_tasks[TASK_BT_INDICATOR] = PL_start_task(TASK_BT_INDICATOR, PL_bt_indicator, NULL, SCHED_BATCH, 0);
  G_iris_tasks[TASK_MATRIX] = PL_start_task(TASK_MATRIX, PL_matrix_analyser_thread, NULL, SCHED_RR, 96);
  G_iris_tasks[TASK_AMP_HW_CTRL] = PL_start_task(TASK_AMP_HW_CTRL, PL_HW_amp_control_thread, NULL, SCHED_RR, 97);
  G_iris_tasks[TASK_BTCTRL] = PL_start_task(TASK_BTCTRL, PL_bluetoothctl_proxy_thread, NULL, SCHED_RR, 98);
  G_iris_tasks[TASK_BTPLAYERCTRL] = PL_start_task(TASK_BTPLAYERCTRL, PL_bluetoothplayer_proxy_thread, NULL, SCHED_RR, 99);
  G_iris_tasks[TASK_MATRIX_DISPLAY] = PL_start_task(TASK_MATRIX_DISPLAY, PL_matrix_display_thread, NULL, SCHED_RR, 95);
  G_iris_tasks[TASK_WEATHER_API] = PL_start_task(TASK_WEATHER_API, PL_weather_api_thread, NULL, SCHED_BATCH, 0);
  G_iris_tasks[TASK_WEATHER_SCENERY] = PL_start_task(TASK_WEATHER_SCENERY, PL_weather_scenery_thread, NULL, SCHED_RR, 81);

  if(G_config.www_access)
   G_iris_tasks[TASK_WEBSRV] = PL_start_task(TASK_WEBSRV, PL_websrv_thread, NULL, SCHED_BATCH, 0);

  usleep(1000);

  if(PL_load_persistence_data(&persistence_data))
   {
    PL_debug("main: syncing persistence data");
    PL_keep_persistence(&persistence_data);
   }
  else
    PL_debug("main: persistence data not found or corrupted");

  G_iris_tasks[TASK_PERSISTENCE] = PL_start_task(TASK_PERSISTENCE, PL_persistence_thread, NULL, SCHED_BATCH,0);

  if(!G_config.bt_spk)
   sleep(4);
  else
   sleep(20);  // we are trying to connect with BT speaker now - wait a bit more

  if(G_config.autoplay)
   {
    if(G_player_mode == PLAYER_STOP)  // if user already started playback - abort autoplay
     {
      PL_debug("main: starting autoplay");
      G_player_mode = PLAYER_STREAM;
     }
   }

  usleep(1000);
 
  PL_debug("main: startup complete");
 
  while(1) { G_global_timer++; sleep(1); }  

 }

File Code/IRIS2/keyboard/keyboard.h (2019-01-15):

#include <bcm2835.h>

#define KEYS_NO 8

enum keypad_keys { KEY1,KEY2,KEY3,KEY4,KEY5,KEY6,KEY7,KEY8 };

#define KEYPAD_CLK RPI_BPLUS_GPIO_J8_13
#define KEYPAD_LATCH RPI_BPLUS_GPIO_J8_15
#define KEYPAD_DATA RPI_BPLUS_GPIO_J8_16

#define ENCODER_L RPI_BPLUS_GPIO_J8_11
#define ENCODER_R RPI_BPLUS_GPIO_J8_07

void PL_keyboard_thread(void);

#define KEY_RADIO_ONOFF        1
#define KEY_RADIO_ONOFF_LONG   130
#define KEY_SETUP              2
#define KEY_SETUP_LONG         131
#define KEY_TUNING_DOWN        4
#define KEY_TUNING_DOWN_LONG   133
#define KEY_TUNING_UP          8
#define KEY_TUNING_UP_LONG     137
#define KEY_VOL_DOWN           64
#define KEY_VOL_DOWN_LONG      193
#define KEY_VOL_UP             128
#define KEY_VOL_UP_LONG        129
#define KEY_SNOOZE_LEFT        16
#define KEY_SNOOZE_LEFT_LONG   145
#define KEY_SNOOZE_CENTER      32
#define KEY_SNOOZE_CENTER_LONG 161

#define KEY_DELAY_NORMAL 100
#define KEY_DELAY_FAST 50
#define KEY_DELAY_FASTER 20

#define THRESHOLD1 50
#define THRESHOLD2 230
#define THRESHOLD3 400

#define ENCODER_TURN_RIGHT 1
#define ENCODER_TURN_LEFT  2
#define ENCODER_NO_EVENT   0

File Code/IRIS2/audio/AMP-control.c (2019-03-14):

#include "global.h"
#include "audio.h"
#include "AMP-TAS5721.h"

void PL_set_amp(uint8_t mode)
 {
   if(mode==1)
    {
     PL_HW_enable_amp();
     G_amp_active = 1;
    }
   else if(mode==0)
    {
     PL_HW_shutdown_amp();
     G_amp_active = 0;
    }
 }

uint8_t PL_init_amp()
 {
   uint8_t result;
   G_config.HW_volume_L = AMP_INIT_SATELLITE_GAIN;
   G_config.HW_volume_R = AMP_INIT_SATELLITE_GAIN;
   G_config.HW_volume_S = AMP_INIT_SUBWOOFER_GAIN;
   G_config.HW_mastervol =  AMP_INIT_MASTERVOL;

   bcm2835_i2c_begin();
   bcm2835_i2c_set_baudrate(TAS5721_I2C_BAUDRATE);
   bcm2835_i2c_setClockDivider(BCM2835_I2C_CLOCK_DIVIDER_2500);

   if(!PL_HW_init_amp()) return 0;
   if(!PL_HW_set_amp_HW_volume(G_config.HW_volume_L,G_config.HW_volume_R,G_config.HW_volume_S,G_config.HW_mastervol)) return 0;
   return 1;
 }


void PL_HW_amp_control_thread()
 {

   uint8_t HW_params[4];
   uint8_t HW_params_prev[4];

   PL_HW_set_amp_HW_volume(G_config.HW_volume_L,G_config.HW_volume_R,G_config.HW_volume_S,G_config.HW_mastervol);

   while(1)
    {

     HW_params[0] = G_config.HW_volume_L;
     HW_params[1] = G_config.HW_volume_R;
     HW_params[2] = G_config.HW_volume_S;
     HW_params[3] = G_config.HW_mastervol;

      if(memcmp(HW_params,HW_params_prev,sizeof(HW_params)))
       {
        PL_HW_set_amp_HW_volume(G_config.HW_volume_L,G_config.HW_volume_R,G_config.HW_volume_S,G_config.HW_mastervol);
       }
     
     HW_params_prev[0] = G_config.HW_volume_L;
     HW_params_prev[1] = G_config.HW_volume_R;
     HW_params_prev[2] = G_config.HW_volume_S;
     HW_params_prev[3] = G_config.HW_mastervol;

     usleep(10000);
    }

 }

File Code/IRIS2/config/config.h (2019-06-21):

uint8_t PL_save_config(void);
void PL_persistence_thread(void);


#define CONFIG_ATTR_STREAM 652
#define CONFIG_ATTR_RSS 344
#define CONFIG_ATTR_ALARM  525
#define CONFIG_ATTR_VOLUME 664
#define CONFIG_ATTR_SLEEP_TIMER 1177
#define CONFIG_ATTR_SNOOZE_TIMER 1310
#define CONFIG_ATTR_SAY_HOUR 1404
#define CONFIG_ATTR_TIMEZONE 875
#define CONFIG_ATTR_WIFI_SSID 961
#define CONFIG_ATTR_WIFI_PSK 1409
#define CONFIG_ATTR_WIFI_TYPE 976
#define CONFIG_ATTR_WIFI_DRIVER 1178
#define CONFIG_ATTR_USE_NTP 766
#define CONFIG_ATTR_NTP_SERVER 1096
#define CONFIG_ATTR_SSH_ACCESS 1055
#define CONFIG_ATTR_WWW_ACCESS 1078
#define CONFIG_ATTR_IP_ADDR 1054
#define CONFIG_ATTR_IP_MASK 1067
#define CONFIG_ATTR_IP_GW 1066
#define CONFIG_ATTR_DEBUG 519
#define CONFIG_ATTR_BASIC_MENU 1046
#define CONFIG_ATTR_AUTOPLAY 879
#define CONFIG_ATTR_ALARM_SOUND 1173
#define CONFIG_ATTR_BT_SPK 643
#define CONFIG_ATTR_BT_SINK 746
#define CONFIG_ATTR_BT_SPEAKER 1056
#define CONFIG_ATTR_BT_SOURCE 966
#define CONFIG_ATTR_TTS_SPEED 971
#define CONFIG_ATTR_TTS_PITCH 978
#define CONFIG_ATTR_TTS_VOL 1106
#define CONFIG_ATTR_TELL_TIME 959
#define CONFIG_ATTR_MATRIX_BRIGHTNESS 1837
#define CONFIG_ATTR_HW_VOL_SATELLITE 2044 
#define CONFIG_ATTR_HW_VOL_SUBWOOFER 2065
#define CONFIG_ATTR_HW_VOL_MASTER 1729
#define CONFIG_ATTR_BT_PAIR_WITH 1276
#define CONFIG_ATTR_FFT_BASE_COL 1464
#define CONFIG_ATTR_FFT_MARKER_COL 1695
#define CONFIG_ATTR_MATRIX_CLOCK_COL 1918
#define CONFIG_ATTR_GET_WEATHER 1167
#define CONFIG_ATTR_MATRIX_TEMP 1954
#define CONFIG_ATTR_MATRIX_WEATHER 1508
#define CONFIG_ATTR_WEATHER_LOCATION 1704
#define CONFIG_ATTR_RAPIDAPI_WEATHER_KEY 2113

// end

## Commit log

2018-12-27 - fixed makefile dependencies - adjusted keypad code to new keypad board with SN74165 parallel to serial shift register - moved main.c to separate dir - added system scripts required for building app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
    [keyboard-thread.c, keyboard.h, main.c]
2018-12-28 - fixed matrix bug (displaying frozen old FFT data when waiting for next stream to buffer) - moved matrix/fft to separate source file
    [global.h, keyboard-thread.c]
2019-01-15 bugfixes, cleanups, matrix clock, some other stuff
    [global.h, keyboard-thread.c, keyboard.h]
2019-03-06 - fixed encoder bug - fixed matrix brightness bug - added matrix brightness setting - some BT stuff
    [config.h, global.h, keyboard-thread.c]
2019-03-07 Started audio amplifier control abstraction layer and TAS5721 driver
2019-03-09 Amplifier control abstraction layer + TAS5721 driver (almost done)
2019-03-13 - fixed bluetooth sink bug - clock on matrix reactivated
    [global.h]
2019-05-19 config parsing bug fix and some config system improvements
    [config.h]
2019-05-19 Added current STL files for the project
    [32x64 P2.5 mount frame single.stl, Main Unit - back cover.stl, Main Unit - key descriptions v3.stl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]
2019-05-19 Started adding project files for hardware
    [Audio Board-B.Cu.gbr, Audio Board-B.Mask.gbr, Audio Board-B.Paste.gbr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]
2019-05-19 cleaning up board projects
    [Audio Board-v2.csv, RTC Board.csv, RTC Board.sch]
2019-05-19 Adding power distribution board project files
    [Power Board-B.Cu.gbr, Power Board-B.Mask.gbr, Power Board-B.Paste.gbr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]
2019-05-19 Adding keypad board project files
    [Keypad-B.Cu.gbr, Keypad-B.Mask.gbr, Keypad-B.Paste.gbr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]
2019-05-19 Adding documentation
    [Interconnections.ods]
2019-05-19 Adding rest of the boards
    [Encoder assembly 1.kicad_pcb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]
